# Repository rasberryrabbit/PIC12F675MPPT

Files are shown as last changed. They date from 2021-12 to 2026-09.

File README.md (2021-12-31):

# PIC12F675MPPT
Solar MPPT circuit.  
  
This is simple MPPT for solar panel.  
New 3.2 firmware from 16F676 project.  
Test is ok as expected. ( jan 18 2019 )  
It's 50W limit design. Consider D6,D1,D2,L1 with more high power solar panel.  
  
11 mili-ohm N-ch logic level FET(BUK9511 or BUK9508) used for current sensor. 
It can replace by 11 mili-ohm or lower Rds-on resistance logic level FET.  
  
Transistor 2N2222A -> BC547 or compatible(reverse pin order)  
Transistor 2N2907A -> BC557 or compatible(reverse pin order)  
  
L1 100~330uH  
  
LM358N can replace by other pin-compatible regular OP-AMP. TLC272 is more works better.  
  
D8-D9 used for 3.6v Reference. Each has about 1.8v voltage drop.  
  
Q1 gate voltage is 3.6v. It's depend on FET specification.  
  
Q1, Q2 can skip heat spreader with low POWER Solar panel. No heat with 10W panel.  
  
(Note) Sometimes MPPT stalls no output. It caused by low FET bootstrap voltage.  
It's very rare condition. It may fixed by R9 change.

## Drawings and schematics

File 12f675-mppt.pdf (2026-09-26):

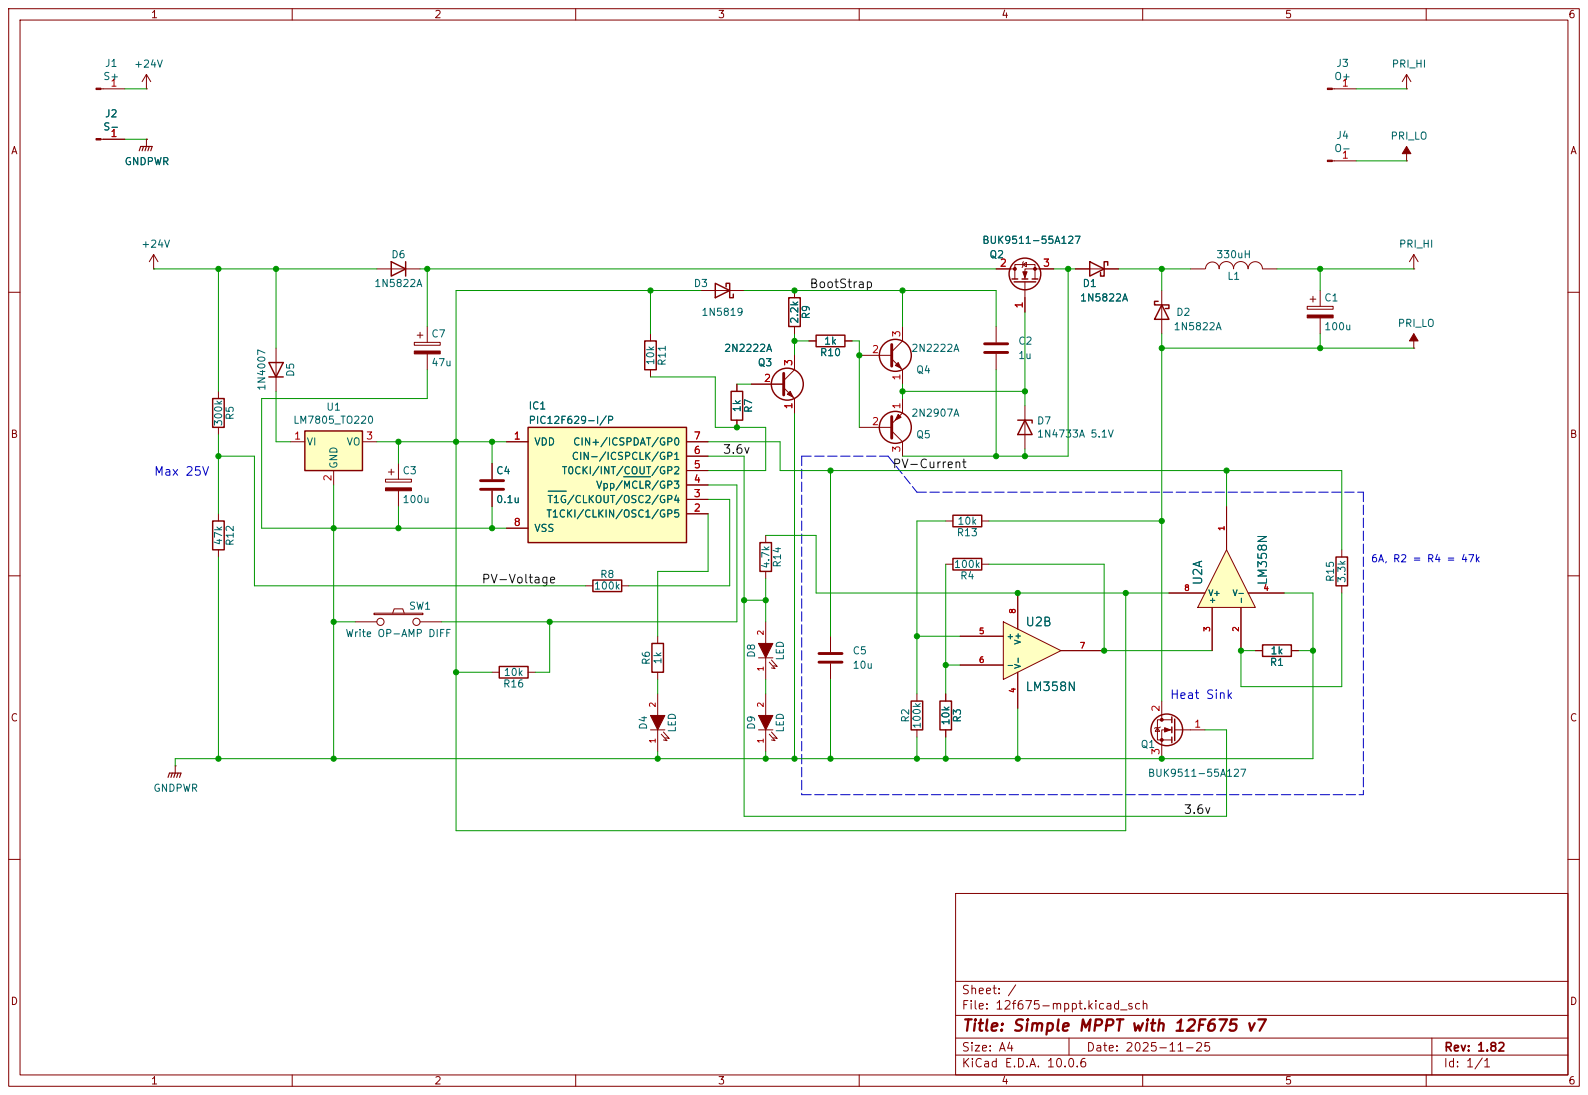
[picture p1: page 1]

SW1 Write OP-AMP DIFF

File: 12f675-mppt.kicad_sch
Title: Simple MPPT with 12F675 v7

Size: A4 | Rev: 1.82
KiCad E.D.A. 10.0.6 | Id: 1/1

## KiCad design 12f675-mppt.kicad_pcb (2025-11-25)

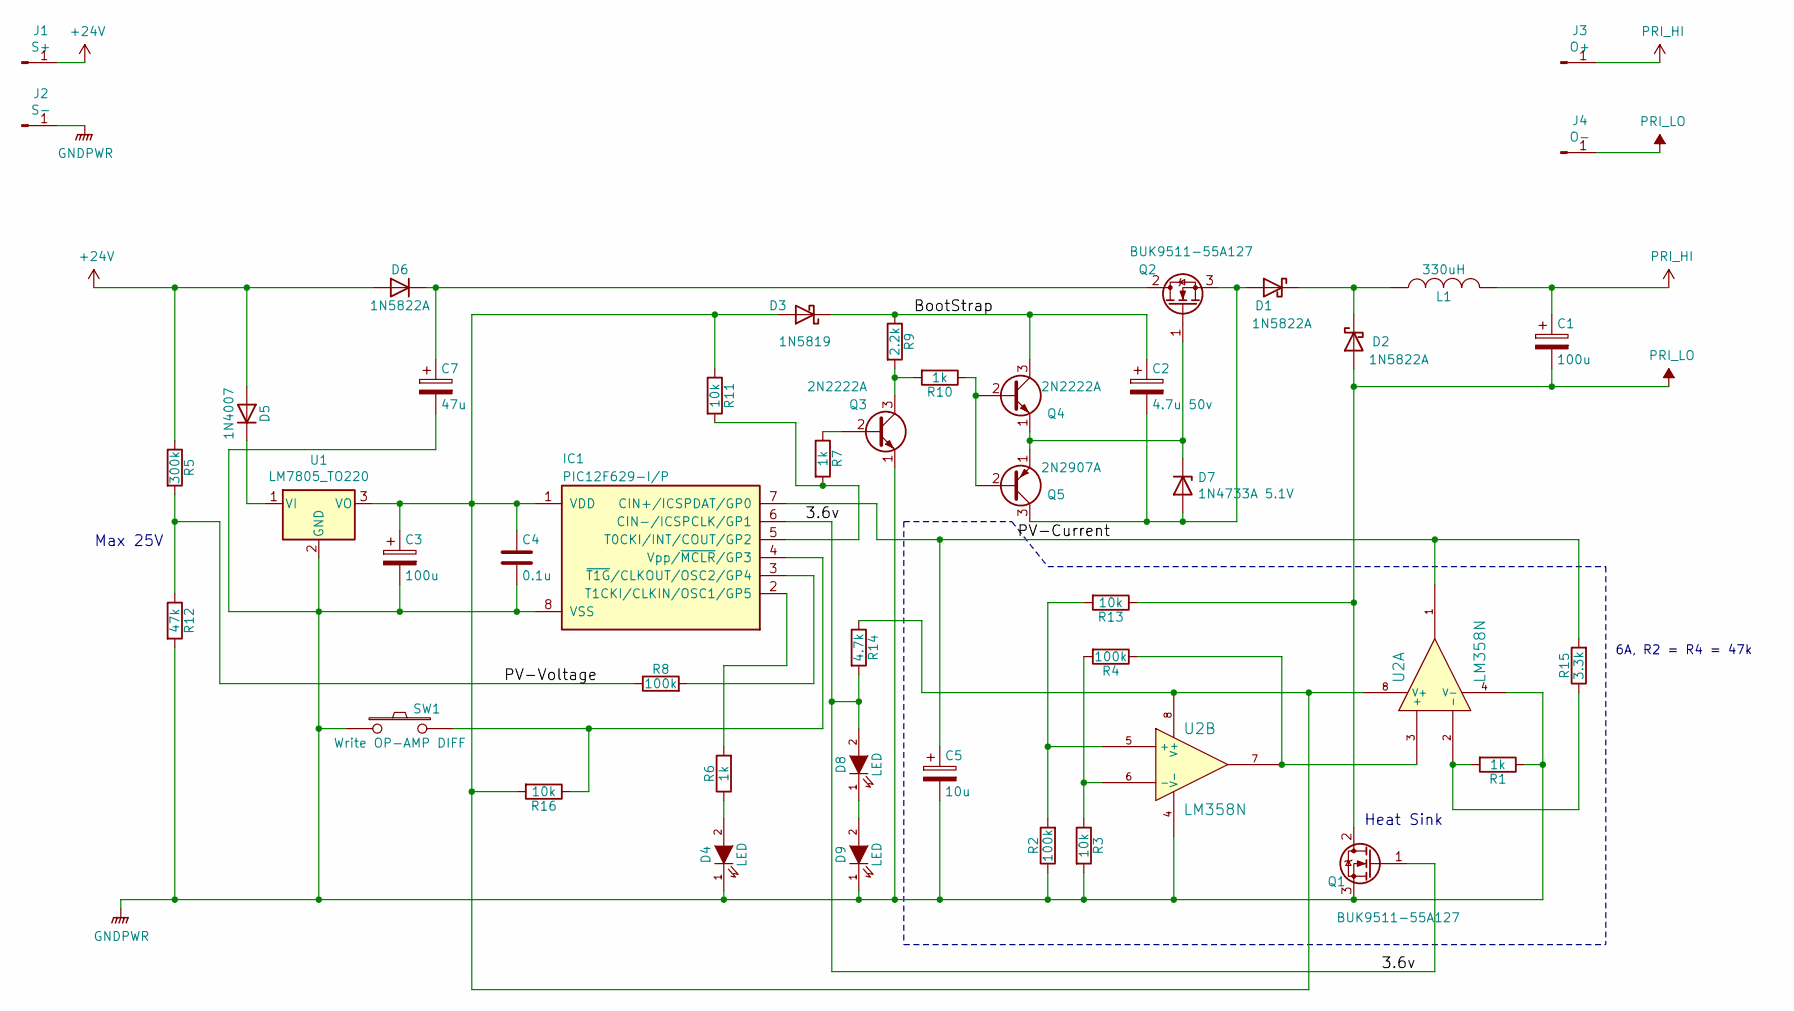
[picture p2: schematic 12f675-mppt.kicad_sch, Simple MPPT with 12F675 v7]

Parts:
C1, C3: 100u; CP_Radial_D12.5mm_P5.00mm
C2: 4.7u 50v; CP_Radial_D12.5mm_P5.00mm
C4: 0.1u; C_Disc_D7.5mm_W4.4mm_P5.00mm
C5: 10u; CP_Radial_D12.5mm_P5.00mm
C7: 47u; CP_Radial_D12.5mm_P5.00mm
D1, D2, D6: 1N5822A; D_DO-201AD_P15.24mm_Horizontal
D3: 1N5819; D_DO-41_SOD81_P10.16mm_Horizontal
D4, D8, D9: LED; LED_D4.0mm
D5: 1N4007; D_DO-41_SOD81_P10.16mm_Horizontal
D7: 1N4733A 5.1V; D_DO-41_SOD81_P10.16mm_Horizontal
IC1: PIC12F629-I/P; DIP-8_W7.62mm_LongPads
J1: S+; 1pin
J2: S-; 1pin
J3: O+; 1pin
J4: O-; 1pin
L1: 330uH; L_Toroid_Vertical_L33.0mm_W17.8mm_P12.70mm_Pulse_KM-5
Q1, Q2: BUK9511-55A127; TO-220-3_Vertical
Q3, Q4: 2N2222A; TO-92_Inline_Wide
Q5: 2N2907A; TO-92_Inline_Wide
R1, R6, R7, R10: 1k; R_Axial_DIN0309_L9.0mm_D3.2mm_P12.70mm_Horizontal
R2, R4, R8: 100k; R_Axial_DIN0309_L9.0mm_D3.2mm_P12.70mm_Horizontal
R3, R11, R13, R16: 10k; R_Axial_DIN0309_L9.0mm_D3.2mm_P12.70mm_Horizontal
R5: 300k; R_Axial_DIN0309_L9.0mm_D3.2mm_P12.70mm_Horizontal
R9: 2.2k; R_Axial_DIN0309_L9.0mm_D3.2mm_P12.70mm_Horizontal
R12: 47k; R_Axial_DIN0309_L9.0mm_D3.2mm_P12.70mm_Horizontal
R14: 4.7k; R_Axial_DIN0309_L9.0mm_D3.2mm_P12.70mm_Horizontal
R15: 3.3k; R_Axial_DIN0309_L9.0mm_D3.2mm_P12.70mm_Horizontal
SW1: Write OP-AMP DIFF; SW_PUSH_6mm
U1: LM7805_TO220; TO-220-3_Vertical
U2: LM358N; DIP-8_W7.62mm_LongPads

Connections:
+24V: D5.2 (A), D6.2 (A), J1.1, R5.1
/3.6v: D8.2 (A), IC1.6 (CIN-/ICSPCLK/GP1), Q1.1 (G), R14.2
/BootStrap: C2.1, D3.1 (K), Q4.3 (C), R9.1
/PV-Current: C5.1, IC1.7 (CIN+/ICSPDAT/GP0), R15.2, U2.1
/PV-Voltage: R5.2, R8.1, R12.1
GNDPWR: C3.2, C4.2, C5.2, C7.2, D4.1 (K), D9.1 (K), IC1.8 (VSS), J2.1, Q1.3 (S), Q3.1 (E), R1.1, R2.1, R3.2, R12.2, SW1.1, U1.2 (GND), U2.4 (V-)
unnamed: C2.2, D1.2 (A), D7.2 (A), Q2.3 (S), Q5.3 (C)
unnamed: D1.1 (K), D2.1 (K), L1.1
unnamed: C3.1, C4.1, D3.2 (A), IC1.1 (VDD), R11.1, R14.1, R16.2, U1.3 (VO), U2.8 (V+)
unnamed: D4.2 (A), R6.1
unnamed: D5.1 (K), U1.1 (VI)
unnamed: C7.1, D6.1 (K), Q2.2 (D)
unnamed: D7.1 (K), Q2.1 (G), Q4.1 (E), Q5.1 (E)
unnamed: D8.1 (K), D9.2 (A)
unnamed: IC1.5 (T0CKI/INT/COUT/GP2), R7.2, R11.2
unnamed: IC1.2 (T1CKI/CLKIN/OSC1/GP5), R6.2
unnamed: IC1.4 (Vpp/~MCLR/GP3), R16.1, SW1.2
unnamed: IC1.3 (~T1G/CLKOUT/OSC2/GP4), R8.2
unnamed: Q3.2 (B), R7.1
unnamed: Q3.3 (C), R9.2, R10.2
unnamed: Q4.2 (B), Q5.2 (B), R10.1
unnamed: R4.1, U2.3 (+), U2.7
unnamed: R1.2, R15.1, U2.2 (-)
unnamed: R2.2, R13.2, U2.5 (+)
unnamed: R3.1, R4.2, U2.6 (-)
PRI_HI: C1.1, J3.1, L1.2
PRI_LO: C1.2, D2.2 (A), J4.1, Q1.2 (D), R13.1

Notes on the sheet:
Max 25V
Heat Sink
6A, R2 = R4 = 47k

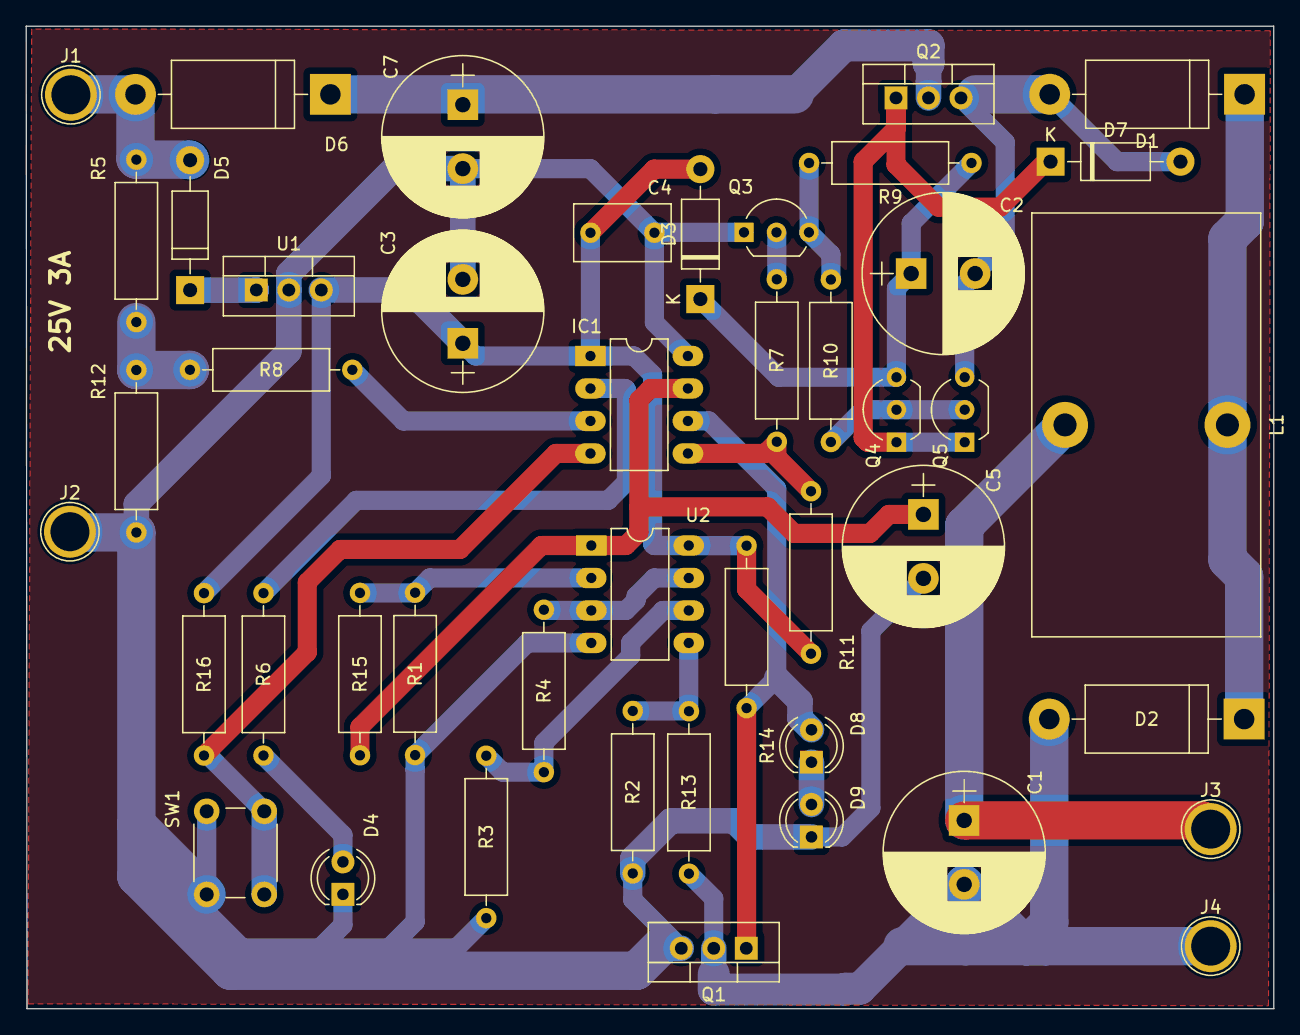
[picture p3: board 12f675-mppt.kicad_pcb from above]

Board: 2 copper layers, 97.6 x 76.8 mm, 45 parts (0 on the bottom side), 27 nets.

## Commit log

2015-08-12 First commit.
    [12f675 MPPT.cfg, 12f675-mppt.sch]
2015-08-13 offset calibration does not work. Change to constant value. 2 is work for upto 14mV(pin 5) at no load. More accuracy read current value.
2015-08-13 More loop count on current check. lower offset current constant.
2015-08-13 Change Schematic. Use Reference voltage(pin 6). More Resistance on FET.
    [12f675-mppt.sch]
2015-08-14 More working on current sensing. Add 1uF capacitor to schematic.
    [12f675-mppt.sch]
2015-08-14 Change constant for testing at low current condition reset. It works ok on normal power supply.
2015-08-15 Correct current sensing.
    [12f675-mppt.sch]
2015-08-15 Remove current comparison.
2015-08-16 Fix circuit and code changes.
    [12f675-mppt.sch]
2015-08-18 Simple is the best. replace loop code for maximum power calibration. Change 100k to 200k ohm because current sensing voltage is too low.
    [12f675-mppt.sch]
2015-08-19 I forgot LM358 offset voltage error.
2015-08-20 Change ADC port reading order.
2015-08-22 Change low pass filter at ADC inputs. Narrows voltage range at solar panel.
    [12f675-mppt.sch]
2015-08-26 Reduce circuit parts. 3,6v to current sensing FET(low value on datasheet is 3v).
    [12f675-mppt.sch]
2015-08-30 Change ADC low pass filter's resisters(10k to 100k). New code.
    [12f675-mppt.sch]
2015-09-03 Remove Timer1 interrupt. More Switching frequency.
2015-09-06 More current, more power.
2015-09-07 Not perfect MPPT, but more power than direct connect.
2015-09-08 Change to new method again. focus on current.
2016-03-13 More safe PWM-on value at low cell power.
2016-03-14 More stable output voltage.
2016-03-14 fix bug at adc values.
2016-03-14 Circuit design changes. more sensivity on current measuring adc.
    [12f675-mppt.sch]
2016-03-14 circuit v3. reduce op-amp amplification.
    [12f675-mppt.sch]
2016-03-17 New method on high power PWM scanning. It may work good and low ripple.
2016-03-18 More power output on high cell power condition. It need more testing.
2016-03-19 Add switch for OP-AMP calibration support. Push on this at no load and OP-AMP offset value write on eeprom.
    [12f675-mppt.sch]
2016-04-15 Set zero at PWM Increasing value when Equal Power level And It read from eeprom. Testing.
2016-06-26 Fix average position on PWM. Finally, solar panel voltage is high on this fix. but make some voltage ripple.
2016-06-26 Reduce switching ripple by preventing zero voltage drop.
2016-06-27 Prevent big drop on PWM.
2016-06-28 Preventing slight drop on PWM. It is working good on osc checking. Vpp is about 8V on solar panel.
2016-07-06 Change PWM Limit divisor.
2016-07-06 Change hi PWM limit divisor.
2016-07-09 Change optimal divisor for hi PWM. It may 4~8 and good with 6.
2016-07-10 Disable "Corr_Vol" and new Correcting avg PWM value.
2016-08-06 More power output. Maximum controled panel voltage to solar panel's adaptive output voltage and don't exceed much.
2018-07-15 make word size and delay 300ms on calibration.
2018-11-18 update capacitor and diode.
    [12f675-mppt.sch]
2018-11-18 reduce timer1 prescaler.
2018-11-30 Implement new method from 16f676 base project.
    [12f675 MPPT.cfg]
2018-11-30 Remove R11. It's a lot lower current sensing voltage.
    [12f675-mppt.sch]
2018-12-17 Remove C6.
    [12f675-mppt.sch]
2019-01-11 Fix R2, R4 value. 300k -> 100k. Add R15 hint.
    [12f675-mppt.sch]
2019-01-11 Fix D6 value.
    [12f675-mppt.sch]
2019-01-28 add PCB layout.
    [12f675-mppt-B.Cu.gbr, 12f675-mppt-B.Mask.gbr, 12f675-mppt-B.SilkS.gbr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]
2019-02-13 Enable BOD.
    [12f675 MPPT.cfg]
2019-02-13 Fix High-z turn on FET problem.
    [12f675-mppt.sch]
2019-02-13 update PCB.
    [12f675-mppt-B.Cu.gbr, 12f675-mppt-B.Mask.gbr, 12f675-mppt-B.SilkS.gbr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]
2019-02-15 Change low PWM for boot strap charging.
2019-02-15 Fix R1, R15 values.
    [12f675-mppt.sch]
2019-02-16 Fix current sensing.
2019-02-24 Update current sensing resistors.
    [12f675-mppt.sch]
2019-05-05 Disable sync with PWM clock.
2019-05-06 Enable PWM checking.
2019-05-20 Change circuit. Exchange GP0(Current Sensing) and GP2(PWM).
    [12f675-mppt.kicad_pcb, 12f675-mppt.sch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]
2019-06-09 Remove low voltage protection code.
2021-04-30 Add FET protection zener diode.
    [12f675-mppt.kicad_pcb, 12f675-mppt.sch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]
2021-05-07 R9 -> 2.2k
    [12f675-mppt.kicad_pcb, 12f675-mppt.sch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]
2021-06-30 Set low PWM to 12.
2021-07-09 C2 to 4.7uF.
    [12f675-mppt.sch]
2021-07-30 Fix FET Bootstrap problem.
    [12f675-mppt.kicad_pcb, 12f675-mppt.sch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]
2021-07-30 Revert PWM_MIN.
2021-07-30 Revert and Change diode.
    [12f675-mppt.kicad_pcb, 12f675-mppt.sch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]
2021-08-01 Fix power comparison.
2025-11-25 Fix circuit. R1 -> 1k
    [12f675-mppt.kicad_pcb, 12f675-mppt.kicad_sch]
2025-12-01 Update PCB files.
    [12f675-mppt-B_Cu.gbr, 12f675-mppt-B_Mask.gbr, 12f675-mppt-B_Silkscreen.gbr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]
2025-12-01 Fix PWM.
2025-12-01 Remove some files.
    [12f675-mppt-B_SilkS.gbr, 12f675-mppt-F_SilkS.gbr]
2025-12-01 More PWM update.
2026-07-23 Try to fixing low power condition when decreasing PV power.
2026-07-31 Remove voltage multiplication operation.
2026-07-31 Change the current measurement method
2026-08-12 Restore voltage multiplier.
2026-08-13 Loosen power low checking.
2026-08-13 Use ADC average values.
2026-09-09 Add reset by button.
2026-09-22 Use dead band for more power output.
2026-09-23 Disable low current checking.
2026-09-24 Try to fix stalling.
2026-09-25 To more reliably compare cumulative power changes, we adjust the update time and limit the maximum deadband at high powers to less than 1%.
2026-09-25 Update PWM @ no load.
2026-09-26 Change capacitors.
    [12f675-mppt.kicad_sch]
